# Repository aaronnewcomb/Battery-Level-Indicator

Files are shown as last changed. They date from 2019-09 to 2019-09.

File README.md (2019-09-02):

# Battery-Level-Indicator
Simple circuit for detecting when LiPo batteries drop below a certain level

# What is it?
A small circuit that uses an Attiny 13A microcontroller to measure the voltage of a 3.7V LiPo battery and sends a signal to another device when the voltage gets to a certain level.

# Theory of operation
The Attiny is supplied by a steady 5V (important for voltage reference). One of the ADCs measures the voltage level of the battery. When the voltage drops below a certain level, the Attiny will set another pin high. This signal goes through a voltage divider to lower it from 5V to 3.3V for compliance with 3.3V tolerant IO pins. This way you can tell another device like a Raspberry Pi that the battery is low and you should shut the device down either manually or programatically. The battery leval at which the signal is triggered can be adjusted with the potentiometer on the board or in the Arduino program that runs on the Attiny. The program should work on any pin compatible version of the Attiny (i.e. Attiny25, 85, etc).

This is especially useful when using a cheap battery charger that doesn't have this functionality built in like this one.
https://www.ebay.com/itm/Lithium-Li-ion-18650-3-7V-4-2V-Battery-Charger-Board-DC-DC-Step-Up-Boost-Module/232791040584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

You can also buy more robust charging circuits that are slightly more expensive and include a low battery indication like this one from Adafruit.
https://www.adafruit.com/product/2465

You could also use this board as a easy way to program 8 pin Attiny's without having to use a breadboard.

# Programming
Program the Attiny13 with an Arduino Uno. 

https://create.arduino.cc/projecthub/taunoerik/programming-attiny13-with-arduino-uno-07beba

Program the Attiny 25,45,85 with an Arduino Uno.

https://create.arduino.cc/projecthub/arjun/programming-attiny85-with-arduino-uno-afb829

I have labeled the pins on the board with the Uno pins they should be connected to.

# Usage
More coming soon

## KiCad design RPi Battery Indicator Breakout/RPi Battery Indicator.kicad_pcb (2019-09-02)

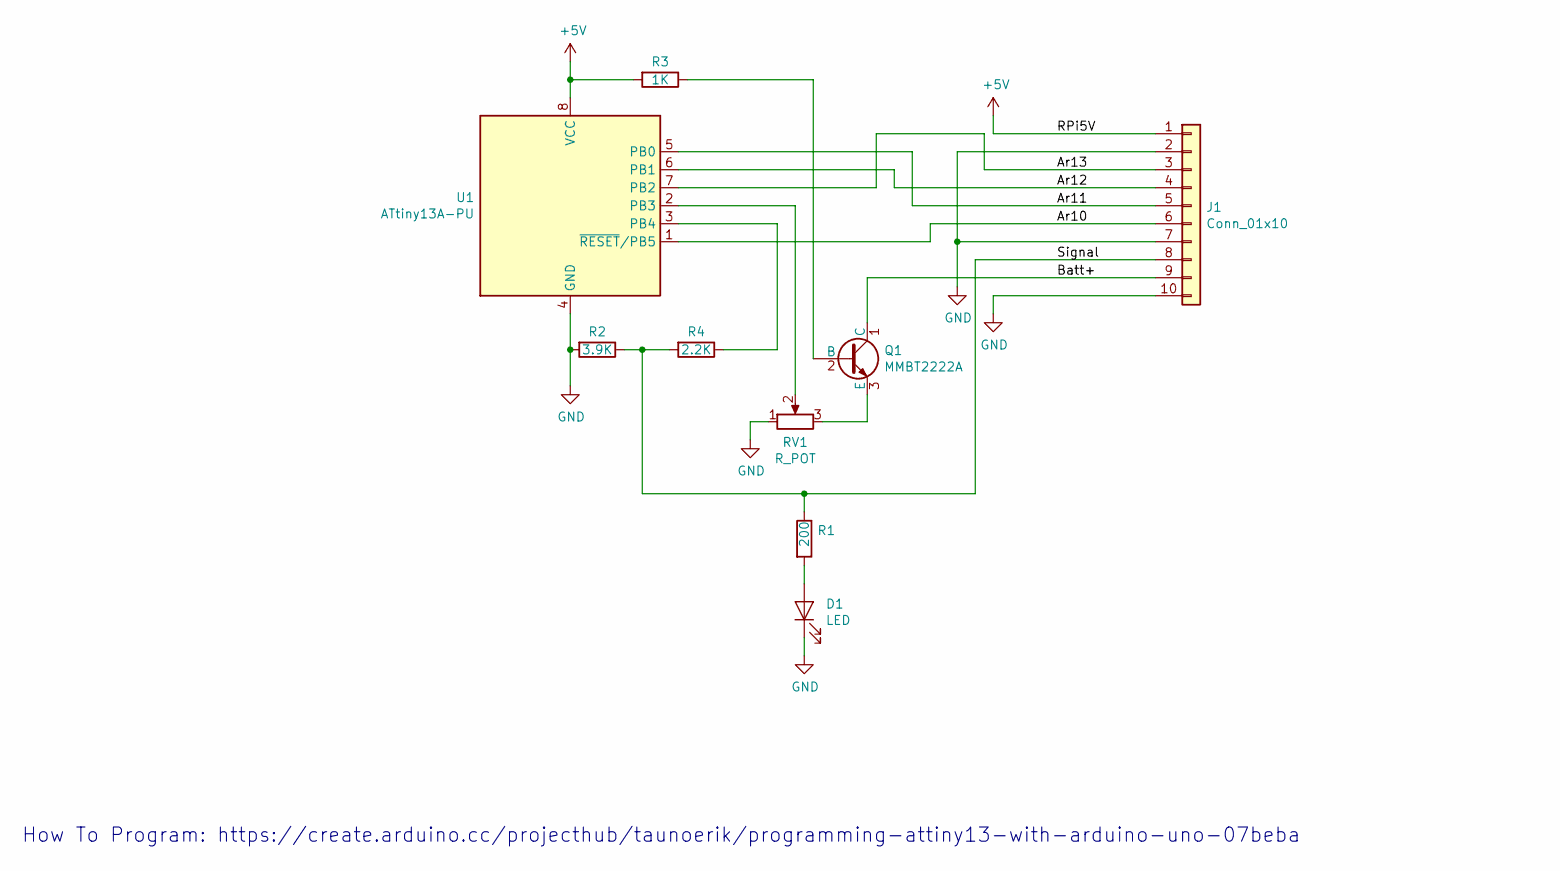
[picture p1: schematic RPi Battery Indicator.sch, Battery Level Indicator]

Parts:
D1: LED; LED_0805_2012Metric
J1: Conn_01x10; PinHeader_1x10_P2.54mm_Vertical
Q1: MMBT2222A; TO-92
R1: 200; R_0805_2012Metric
R2: 3.9K; R_0805_2012Metric
R3: 1K; R_0805_2012Metric
R4: 2.2K; R_0805_2012Metric
RV1: R_POT; Trimpot_3.8mmx3.6mm_TC33X-2-103E
U1: ATtiny13A-PU; DIP-8_W7.62mm

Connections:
+5V: J1.1, R3.2, U1.8 (VCC)
/Ar10: J1.6, U1.1 (~RESET~/PB5)
/Ar11: J1.5, U1.5 (PB0)
/Ar12: J1.4, U1.6 (PB1)
/Ar13: J1.3, U1.7 (PB2)
/Batt+: J1.9, Q1.1 (C)
/Signal: J1.8, R1.1, R2.1, R4.2
GND: D1.1 (K), J1.2, J1.7, J1.10, R2.2, RV1.1, U1.4 (GND)
unnamed: D1.2 (A), R1.2
unnamed: Q1.2 (B), R3.1
unnamed: Q1.3 (E), RV1.3
unnamed: R4.1, U1.3 (PB4)
unnamed: RV1.2, U1.2 (PB3)

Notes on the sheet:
How To Program: https://create.arduino.cc/projecthub/taunoerik/programming-attiny13-with-arduino-uno-07beba

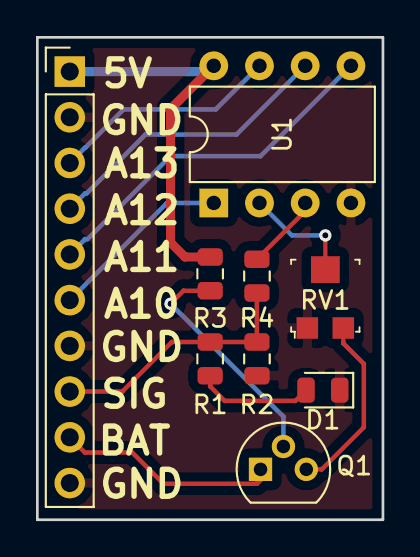
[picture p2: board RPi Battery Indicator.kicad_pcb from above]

Board: 2 copper layers, 19.2 x 26.8 mm, 9 parts (0 on the bottom side), 13 nets.

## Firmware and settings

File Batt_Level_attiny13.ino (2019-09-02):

const int numReadings = 15;
int readings[numReadings];      // the readings from the analog input
int readIndex = 0;              // the index of the current reading
int total = 0;                  // the running total
int average = 0;                // the average
int inputPin = 3;

void setup() {
 // initialize pin 4 (ATtiny leg 3) as an output.
 pinMode(4, OUTPUT);
 for (int thisReading = 0; thisReading < numReadings; thisReading++) {
    readings[thisReading] = 0;
  }
}
void loop() {
  // subtract the last reading:
  total = total - readings[readIndex];
  // read from the sensor:
  readings[readIndex] = analogRead(inputPin);
  // add the reading to the total:
  total = total + readings[readIndex];
  // advance to the next position in the array:
  readIndex = readIndex + 1;

  // if we're at the end of the array...
  if (readIndex >= numReadings) {
    // ...wrap around to the beginning:
    readIndex = 0;
    delay (10000); // take averages every 10 sec
  }

  // calculate the average:
  average = total / numReadings;
  if (average < 350) { //736
    digitalWrite(4, HIGH);   // turn the LED on (HIGH is the voltage level)
  } else {  
    digitalWrite(4, LOW);    // turn the LED off by making the voltage LOW
  }
  delay(1);        // delay in between reads for stability
} 

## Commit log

2019-09-02 Initial file upload
    [RPi Battery Indicator.kicad_pcb, RPi Battery Indicator.sch]
2019-09-02 Changed ADC values to allow for lower voltage detection
